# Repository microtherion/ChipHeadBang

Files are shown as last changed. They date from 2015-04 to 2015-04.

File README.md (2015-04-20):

# ChipHeadBang
Design for an USB to Serial converter with ICSP header for (slow) bitbang programming, based on the CH340G chip. See http://samelimmat.blogspot.com/2015/04/introducing-chipheadbang.html

While this seems to work pretty well, and the CH340G can be obtained extremely cheaply from sources such as 
AliExpress, driver support can be a bit iffy. For current versions of OS X, the vendor provided driver will 
cause kernel panics, and as far as I know, only this commercial alternative will work: https://www.mac-usb-serial.com 

ChipHeadBang top view

Boards can be ordered at OSHPark: https://oshpark.com/shared_projects/xvqfIt55

<br />This work is licensed under a <a rel="license" href="http://creativecommons.org/licenses/by/4.0/">Creative Commons Attribution 4.0 International License</a>.

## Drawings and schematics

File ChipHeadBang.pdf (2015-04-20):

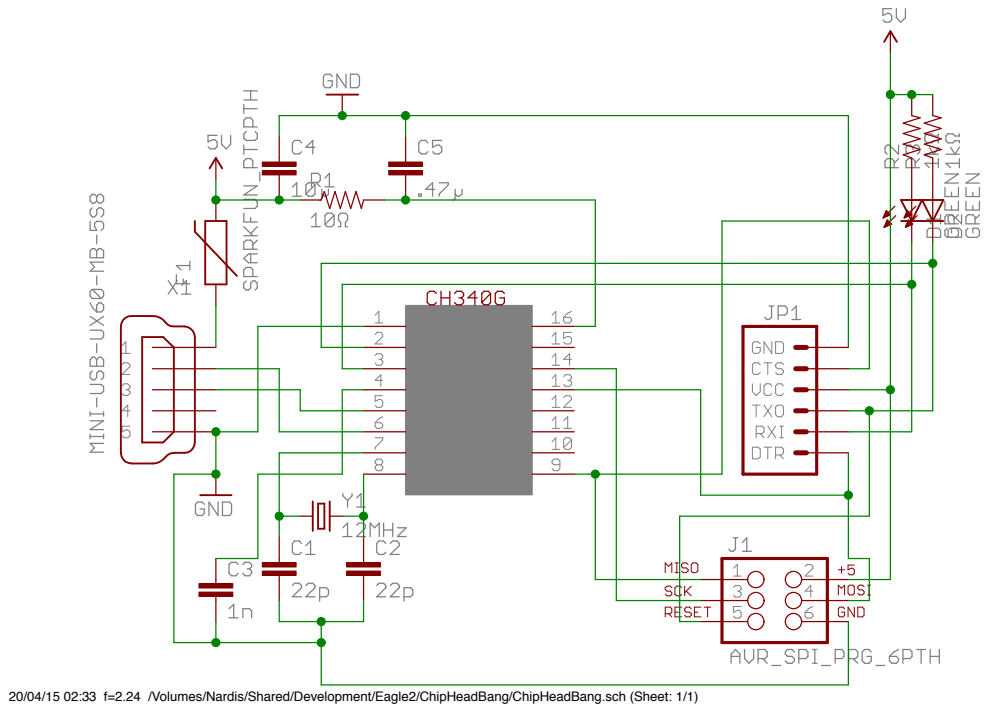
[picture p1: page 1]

20/04/15 02:33 f=2.24 /Volumes/Nardis/Shared/Development/Eagle2/ChipHeadBang/ChipHeadBang.sch (Sheet: 1/1)

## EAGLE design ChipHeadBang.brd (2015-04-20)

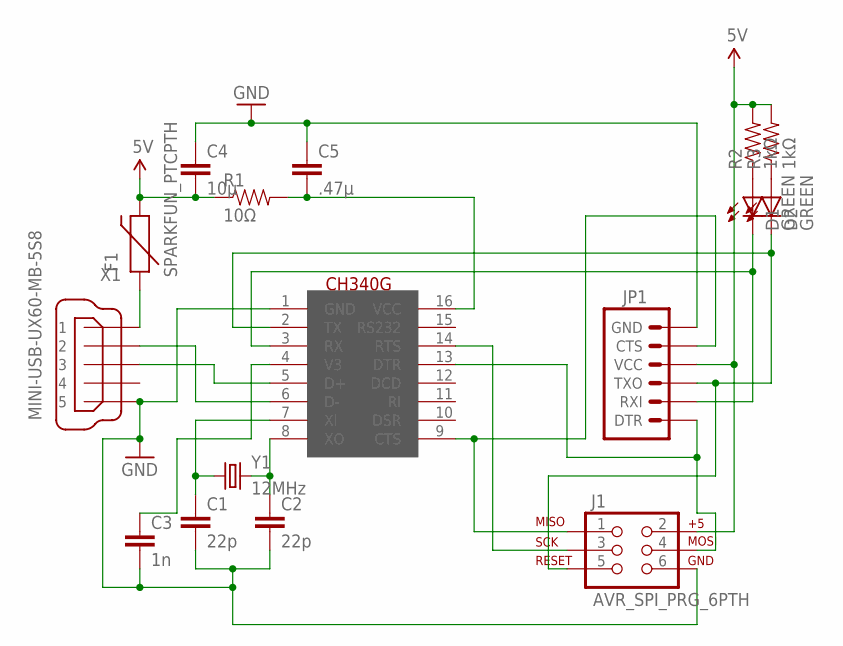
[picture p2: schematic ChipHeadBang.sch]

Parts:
C1, C2: 22p; 0603-CAP
C3: 1n; 0603-CAP
C4: 10µ; 0805
C5: .47µ; 0805
D1, D2: GREEN; LED-1206
F1: SPARKFUN_PTCPTH; SPARKFUN_PTC
J1: AVR_SPI_PRG_6PTH; 2X3
JP1: ARDUINO_SERIAL_PROGRAMPTH; 1X06
R1: 10Ω; 0603-RES
R2, R3: 1kΩ; 0603-RES
U$1: CH340G; SOIC16
X1: MINI-USB-UX60-MB-5S8; UX60-MB-5S8
Y1: 12MHz; SPARKFUN_HC49US

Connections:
5V: C4.2, F1.P$2 (2), J1.2, JP1.4 (VCC), R1.1, R2.2, R3.2
GND: C1.2, C2.2, C3.2, C4.1, C5.1, J1.6, JP1.6 (GND), U$1.1 (GND), X1.5
unnamed: F1.P$1 (1), X1.1
unnamed: U$1.6 (D-), X1.2
unnamed: U$1.5 (D+), X1.3
unnamed: C5.2, R1.2, U$1.16 (VCC)
unnamed: C1.1, U$1.7 (XI), Y1.1
unnamed: C2.1, U$1.8 (XO), Y1.2
unnamed: D1.A, R2.1
unnamed: J1.3, U$1.14 (RTS)
unnamed: C3.1, U$1.4 (V3)
unnamed: D1.C, JP1.2 (RXI), U$1.3 (RX)
unnamed: J1.1, JP1.5 (CTS), U$1.9 (CTS)
unnamed: D2.A, R3.1
unnamed: D2.C, J1.5, JP1.3 (TXO), U$1.2 (TX)
unnamed: J1.4, JP1.1 (DTR), U$1.13 (DTR)

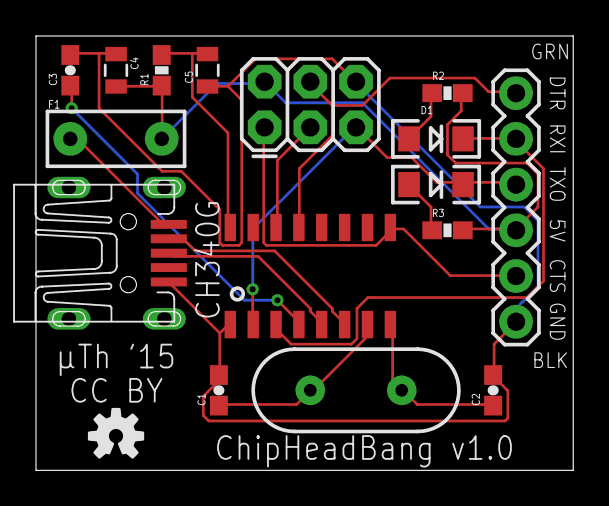
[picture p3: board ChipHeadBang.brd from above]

Board: 2 copper layers, 29.8 x 24.1 mm, 17 parts (0 on the bottom side), 16 nets.

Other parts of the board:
U$2: OSHW-LOGO-S

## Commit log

2015-04-20 Moving ChipHeadBang to separate repo
    [ChipHeadBang.brd, ChipHeadBang.sch]
2015-04-20 Added bill of materials
2015-04-20 Added pdf schematic

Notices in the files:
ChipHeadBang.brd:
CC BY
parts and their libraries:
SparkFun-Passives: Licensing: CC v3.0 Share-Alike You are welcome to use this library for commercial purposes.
